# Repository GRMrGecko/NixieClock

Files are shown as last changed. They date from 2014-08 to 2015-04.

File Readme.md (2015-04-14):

#Nixie Tube Clock - Arduino Controlled Clock

I don't have any fun names to put on this project, I haven't thought of one... If you have one, email me.

All details has not been written out, but you can piece together things by going to my blog at http://mrgecko.org and viewing images and docs here.

You would want to use Modified Board to print as I include the needed gerber files and also it has pin outs for power which is useful for adding the bluetooth board.

Many of the parts used is available at https://www.sparkfun.com/wish_lists/83348 I recommend buying the needed resistors from some place where you can order them individually.

To get nixie tubes, I recommend you go on ebay and search for "Nixie Tube IN 14" without quotes.

Power Supply can be ordered from http://www.allspectrum.com/store/nixie-power-supply-high-voltage-switch-mode-dc-dc-converter-kit-95-190vdc-25ma-180vdc-p-521.html
The tube ICs can be purchased from http://www.allspectrum.com/store/74141-nixie-tube-driver-ic-russian-p-211.html, you will need 6.

Look at notes.txt for resister values.

Extended documents available at https://sf.gec.im/d/1c3d227302/

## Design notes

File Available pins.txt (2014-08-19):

12
8
9
4
3

13 - May not be available due to LED

A4
A5
A0
A1
A2
A3

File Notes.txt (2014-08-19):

1K for temp
10k under arduino
27k for nixies

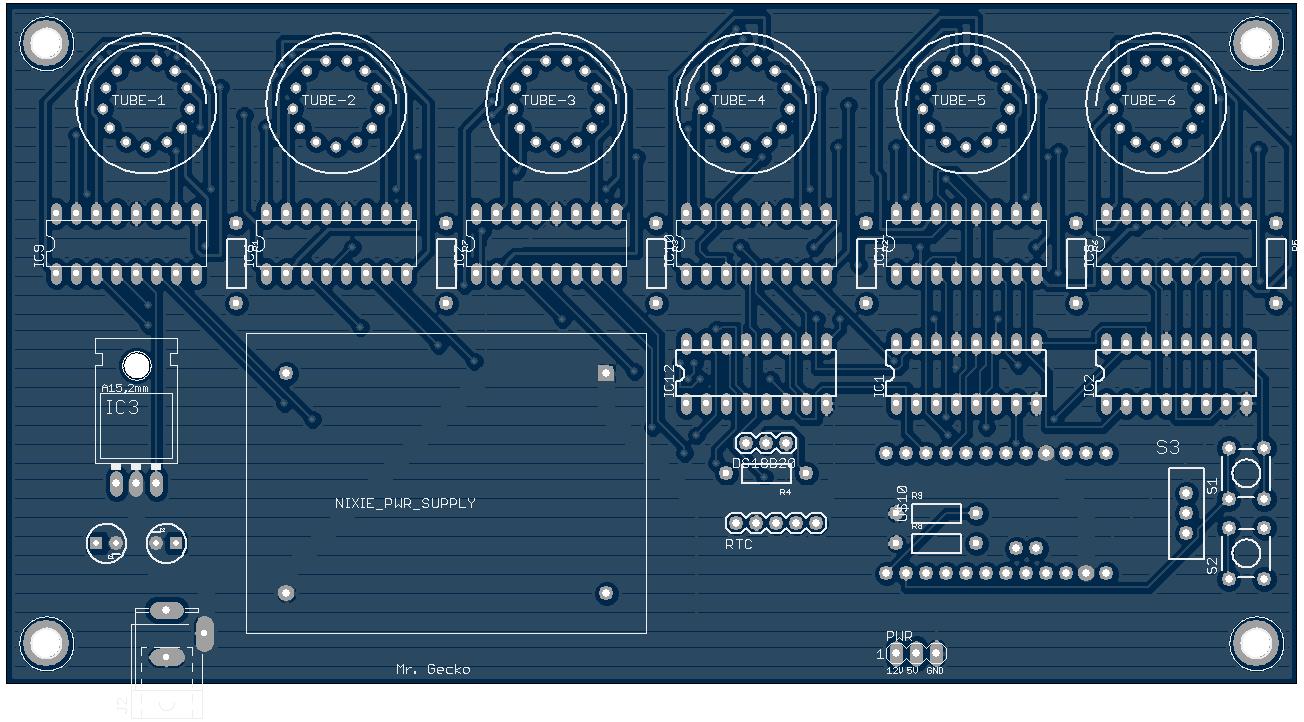
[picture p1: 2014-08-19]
Modified Board/top.png

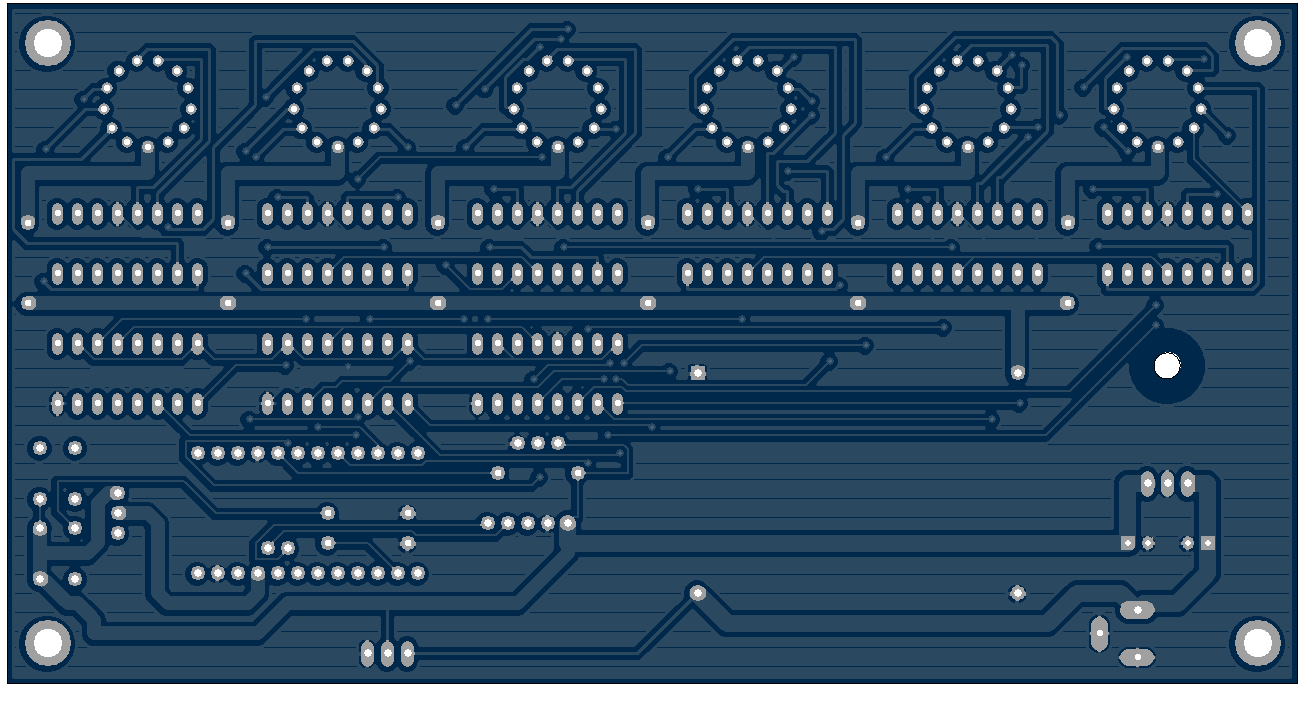
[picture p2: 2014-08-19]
Modified Board/bottom.png

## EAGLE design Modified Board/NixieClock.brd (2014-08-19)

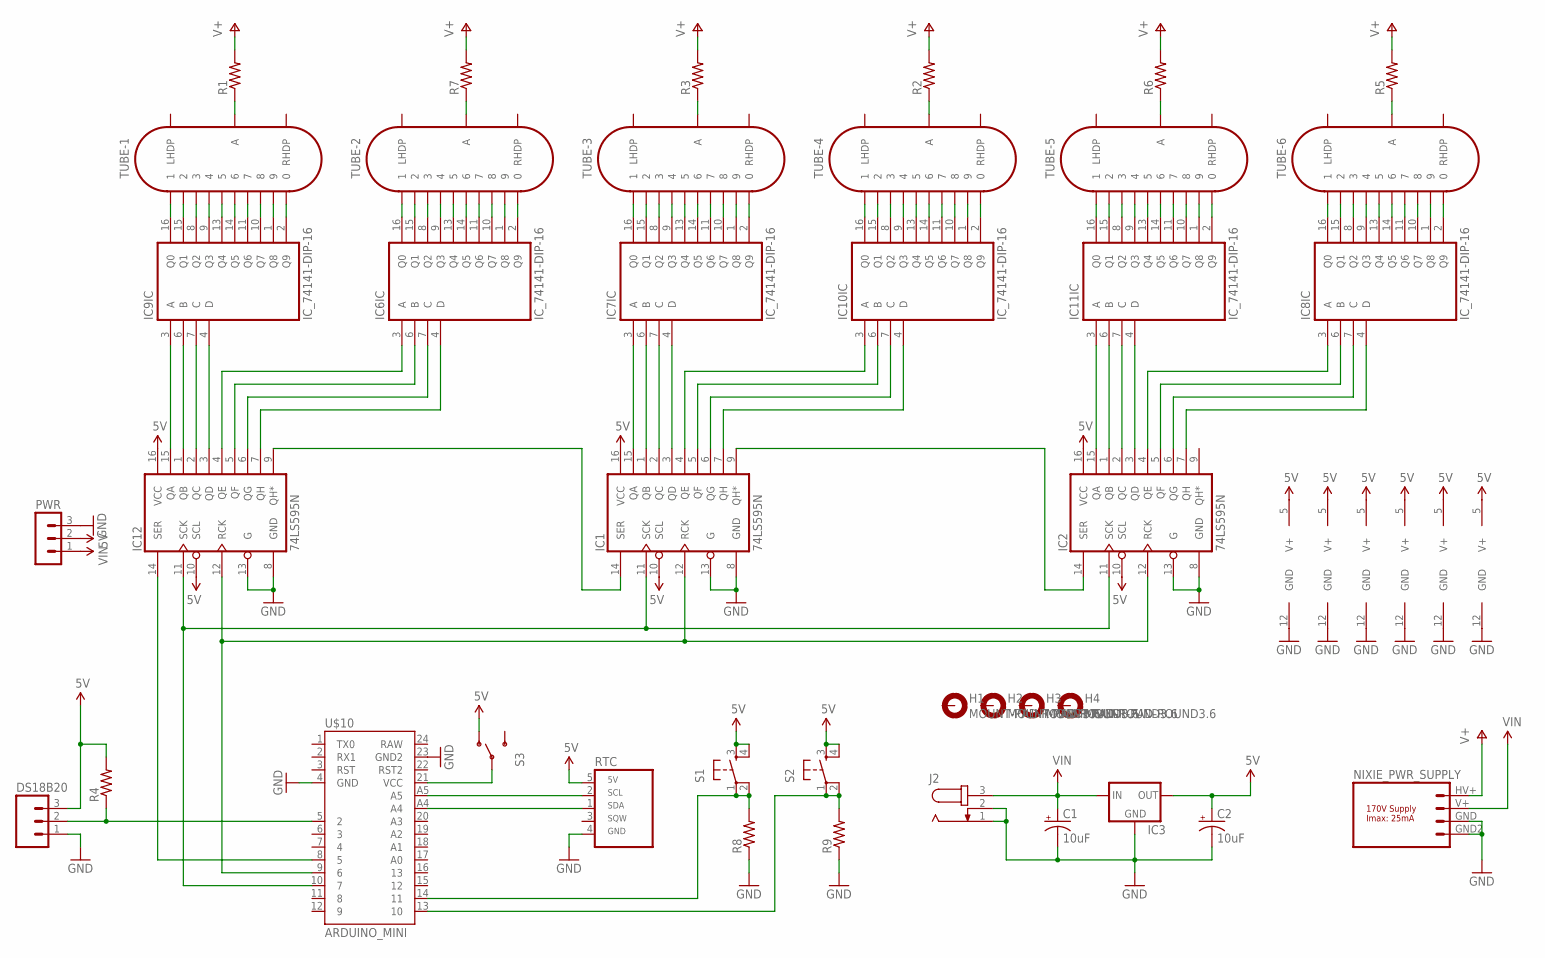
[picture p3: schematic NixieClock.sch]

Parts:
C1, C2: 10uF; CPOL-RADIAL-10UF-25V
DS18B20: DS18B20DS18B20; DS18B20
H1, H2, H3, H4: MOUNT-PAD-ROUND3.6; 3,6-PAD
IC1, IC2, IC12: 74LS595N; DIL16
IC3: V_REG_78XXSIDE; 78XXL
IC6, IC7, IC8, IC9, IC10, IC11: IC_74141-DIP-16; DIL16
J2: JACK-PLUG0; SPC4077
NIXIE_PWR_SUPPLY: NIXIE_PWR_SUPPLYPTH; NIXIE_PWR_SUPPLY
PWR: MA03-1
R1, R2, R3, R4, R5, R6, R7, R8, R9: RESISTORPTH-1/4W; AXIAL-0.4
RTC: SCOTT_RTCPTH; SCOTT_RTC
S1, S2: TAC_SWITCHPTH; TACTILE-PTH
S3: SWITCH-SPDTPTH; SWITCH-SPDT
TUBE-1, TUBE-2, TUBE-3, TUBE-4, TUBE-5, TUBE-6: IN-14
U$10: ARDUINO_MINI

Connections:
5V: C2.1 (+), DS18B20.3 (5V), IC1.10 (SCL), IC1.16 (VCC), IC2.10 (SCL), IC2.16 (VCC), IC3.OUT, IC6.5 (V+), IC7.5 (V+), IC8.5 (V+), IC9.5 (V+), IC10.5 (V+), IC11.5 (V+), IC12.10 (SCL), IC12.16 (VCC), PWR.2, R4.P$2 (2), RTC.5 (5V), S1.3, S1.4, S2.3, S2.4, S3.1 (O)
GND: C1.2 (-), C2.2 (-), DS18B20.1 (GND), IC1.8 (GND), IC1.13 (G), IC2.8 (GND), IC2.13 (G), IC3.GND, IC6.12 (GND), IC7.12 (GND), IC8.12 (GND), IC9.12 (GND), IC10.12 (GND), IC11.12 (GND), IC12.8 (GND), IC12.13 (G), J2.1, J2.2, NIXIE_PWR_SUPPLY.GND (4), NIXIE_PWR_SUPPLY.GND2 (1), PWR.3, R8.P$1 (1), R9.P$1 (1), RTC.4 (GND), U$10.4 (GND), U$10.23 (GND2)
unnamed: R1.P$1 (1), TUBE-1.A
unnamed: R7.P$1 (1), TUBE-2.A
unnamed: R3.P$1 (1), TUBE-3.A
unnamed: R2.P$1 (1), TUBE-4.A
unnamed: R6.P$1 (1), TUBE-5.A
unnamed: R5.P$1 (1), TUBE-6.A
unnamed: IC9.16 (Q0), TUBE-1.1
unnamed: IC9.15 (Q1), TUBE-1.2
unnamed: IC9.8 (Q2), TUBE-1.3
unnamed: IC9.9 (Q3), TUBE-1.4
unnamed: IC9.13 (Q4), TUBE-1.5
unnamed: IC9.14 (Q5), TUBE-1.6
unnamed: IC9.11 (Q6), TUBE-1.7
unnamed: IC9.10 (Q7), TUBE-1.8
unnamed: IC9.1 (Q8), TUBE-1.9
unnamed: IC9.2 (Q9), TUBE-1.0
unnamed: IC6.16 (Q0), TUBE-2.1
unnamed: IC6.15 (Q1), TUBE-2.2
unnamed: IC6.8 (Q2), TUBE-2.3
unnamed: IC6.9 (Q3), TUBE-2.4
unnamed: IC6.13 (Q4), TUBE-2.5
unnamed: IC6.14 (Q5), TUBE-2.6
unnamed: IC6.11 (Q6), TUBE-2.7
unnamed: IC6.10 (Q7), TUBE-2.8
unnamed: IC6.1 (Q8), TUBE-2.9
unnamed: IC6.2 (Q9), TUBE-2.0
unnamed: IC7.16 (Q0), TUBE-3.1
unnamed: IC7.15 (Q1), TUBE-3.2
unnamed: IC7.8 (Q2), TUBE-3.3
unnamed: IC7.9 (Q3), TUBE-3.4
unnamed: IC7.13 (Q4), TUBE-3.5
unnamed: IC7.14 (Q5), TUBE-3.6
unnamed: IC7.11 (Q6), TUBE-3.7
unnamed: IC7.10 (Q7), TUBE-3.8
unnamed: IC7.1 (Q8), TUBE-3.9
unnamed: IC7.2 (Q9), TUBE-3.0
unnamed: IC10.16 (Q0), TUBE-4.1
unnamed: IC10.15 (Q1), TUBE-4.2
unnamed: IC10.8 (Q2), TUBE-4.3
unnamed: IC10.9 (Q3), TUBE-4.4
unnamed: IC10.13 (Q4), TUBE-4.5
unnamed: IC10.14 (Q5), TUBE-4.6
unnamed: IC10.11 (Q6), TUBE-4.7
unnamed: IC10.10 (Q7), TUBE-4.8
unnamed: IC10.1 (Q8), TUBE-4.9
unnamed: IC10.2 (Q9), TUBE-4.0
unnamed: IC11.16 (Q0), TUBE-5.1
unnamed: IC11.15 (Q1), TUBE-5.2
unnamed: IC11.8 (Q2), TUBE-5.3
unnamed: IC11.9 (Q3), TUBE-5.4
unnamed: IC11.13 (Q4), TUBE-5.5
unnamed: IC11.14 (Q5), TUBE-5.6
unnamed: IC11.11 (Q6), TUBE-5.7
unnamed: IC11.10 (Q7), TUBE-5.8
unnamed: IC11.1 (Q8), TUBE-5.9
unnamed: IC11.2 (Q9), TUBE-5.0
unnamed: IC8.16 (Q0), TUBE-6.1
unnamed: IC8.15 (Q1), TUBE-6.2
unnamed: IC8.8 (Q2), TUBE-6.3
unnamed: IC8.9 (Q3), TUBE-6.4
unnamed: IC8.13 (Q4), TUBE-6.5
unnamed: IC8.14 (Q5), TUBE-6.6
unnamed: IC8.11 (Q6), TUBE-6.7
unnamed: IC8.10 (Q7), TUBE-6.8
unnamed: IC8.1 (Q8), TUBE-6.9
unnamed: IC8.2 (Q9), TUBE-6.0
unnamed: IC1.1 (QB), IC7.6 (B)
unnamed: IC1.2 (QC), IC7.7 (C)
unnamed: IC1.3 (QD), IC7.4 (D)
unnamed: IC1.15 (QA), IC7.3 (A)
unnamed: IC9.6 (B), IC12.1 (QB)
unnamed: IC9.7 (C), IC12.2 (QC)
unnamed: IC9.4 (D), IC12.3 (QD)
unnamed: IC9.3 (A), IC12.15 (QA)
unnamed: IC2.1 (QB), IC11.6 (B)
unnamed: IC2.2 (QC), IC11.7 (C)
unnamed: IC2.3 (QD), IC11.4 (D)
unnamed: IC2.15 (QA), IC11.3 (A)
unnamed: IC6.3 (A), IC12.4 (QE)
unnamed: IC6.6 (B), IC12.5 (QF)
unnamed: IC6.7 (C), IC12.6 (QG)
unnamed: IC6.4 (D), IC12.7 (QH)
unnamed: IC1.14 (SER), IC12.9 (QH*)
unnamed: IC1.9 (QH*), IC2.14 (SER)
unnamed: IC1.4 (QE), IC10.3 (A)
unnamed: IC1.5 (QF), IC10.6 (B)
unnamed: IC1.6 (QG), IC10.7 (C)
unnamed: IC1.7 (QH), IC10.4 (D)
unnamed: IC12.14 (SER), U$10.8 (5)
unnamed: IC2.4 (QE), IC8.3 (A)
unnamed: IC2.5 (QF), IC8.6 (B)
unnamed: IC2.6 (QG), IC8.7 (C)
unnamed: IC2.7 (QH), IC8.4 (D)
unnamed: IC1.11 (SCK), IC2.11 (SCK), IC12.11 (SCK), U$10.10 (7)
unnamed: IC1.12 (RCK), IC2.12 (RCK), IC12.12 (RCK), U$10.9 (6)
unnamed: R9.P$2 (2), S2.1, S2.2, U$10.13 (10)
unnamed: DS18B20.2 (DS), R4.P$1 (1), U$10.5 (2)
unnamed: RTC.2 (SCL), U$10.A5
unnamed: RTC.1 (SDA), U$10.A4
unnamed: S3.2, U$10.21 (VCC)
unnamed: R8.P$2 (2), S1.1, S1.2, U$10.14 (11)
V+: NIXIE_PWR_SUPPLY.HV+ (3), R1.P$2 (2), R2.P$2 (2), R3.P$2 (2), R5.P$2 (2), R6.P$2 (2), R7.P$2 (2)
VIN: C1.1 (+), IC3.IN, J2.3, NIXIE_PWR_SUPPLY.V+ (2), PWR.1

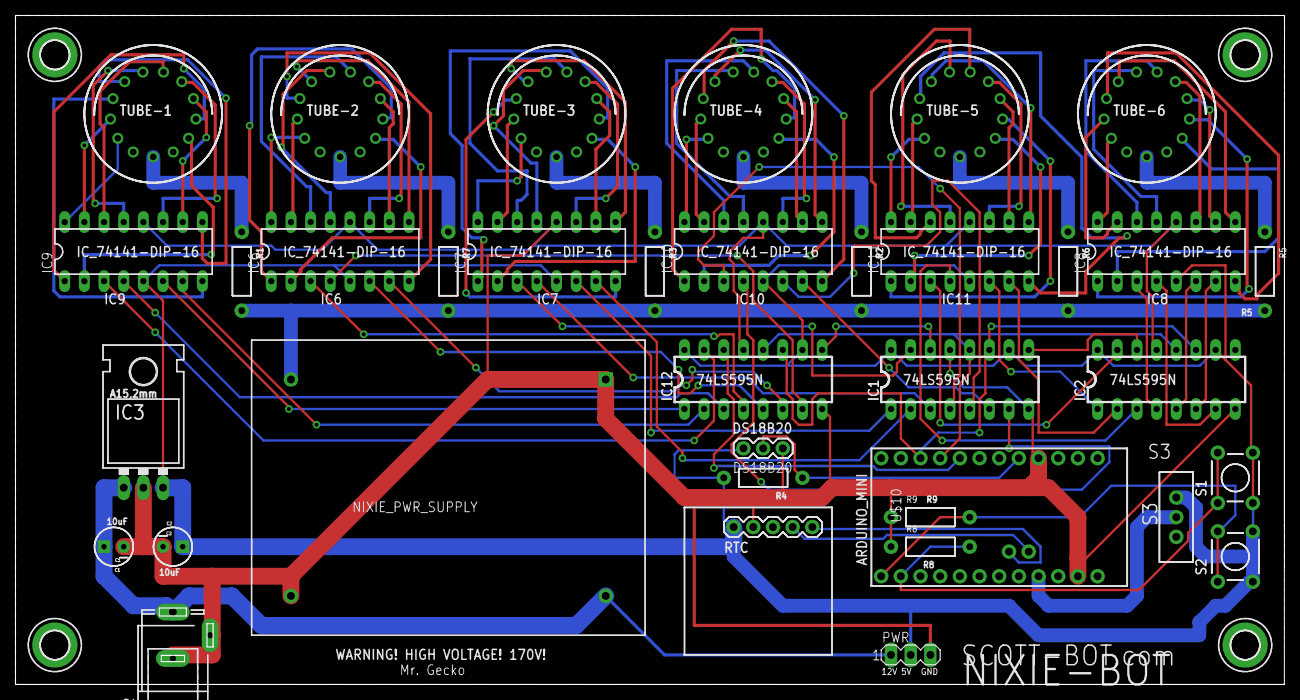
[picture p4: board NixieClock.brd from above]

Board: 2 copper layers, 163.8 x 86.4 mm, 40 parts (0 on the bottom side), 105 nets.

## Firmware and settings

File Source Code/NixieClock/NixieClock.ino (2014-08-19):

//
//  Nixie Clock.ino
//
//  Created by Mr. Gecko's Media (James Coleman) on 7/23/14.
//  No Copyright Claimed. Public Domain.
//

#include <Wire.h>
#include "RTClib.h"
#include "OneWire.h"

#include "Nixies.h"
#include "Registers.h"

const unsigned int button1Pin = 10;
const unsigned int button2Pin = 11;
unsigned int button1State = 0;
unsigned int button2State = 0;

OneWire ds(2); // Temperature Sensor on pin 2
RTC_DS1307 RTC;

unsigned int serialPin = 5;
unsigned int serialClockPin = 7;
unsigned int registerClockPin = 6;

Nixies nixies;

void setup() {
	Serial.begin(9600);
	Wire.begin();
	
	RTC.begin();
	if (!RTC.isrunning()) {
		Serial.println("RTC needs to be set");
		RTC.adjust(DateTime(__DATE__, __TIME__));
	}
	
	pinMode(button1Pin, INPUT);
	pinMode(button2Pin, INPUT);       
	
	nixies.initialize(serialPin, serialClockPin, registerClockPin, 6);
}

void parseSerialData(char *data) {
	char *originalData = data;
	char *array[10];
	int arrayCount = 0;
	
	char *parse = strtok(data, ",");
	while (parse!=NULL) {
		array[arrayCount] = parse;
		arrayCount++;
		if (arrayCount>=9)
			return;
		parse = strtok(NULL, ",");
	}
	array[arrayCount] = NULL;
	
	if (arrayCount==0)
		return;
	if (strcmp(array[0],"pi")==0) {//Ping
		Serial.println(originalData);
	} else if (strcmp(array[0],"st")==0 && arrayCount==8) {// Set Time
		delay(atoi(array[7]));
		RTC.adjust(DateTime(atoi(array[1])/*Year*/, atoi(array[2])/*Month*/, atoi(array[3])/*Day*/, atoi(array[4])/*Hour*/, atoi(array[5])/*Minute*/, atoi(array[6])/*Second*/));
	} else if (strcmp(array[0],"dp")==0 && arrayCount==3) { // Display for MS.
		char *display = array[1];
		int length = strlen(display);
		if (length>6)
			return;
		for (int i=0; i<6; i++) {
			int value;
			if (i<length) {
				char digit = display[i];
				if (digit==' ') {
					value = 10;
				} else {
					value = atoi(&digit);
				}
			} else {
				value = 10;
			}
			nixies.setNixie(5-i, value);
		}
		nixies.update();
		delay(atoi(array[2]));
	} else if (strcmp(array[0],"test")==0) { // Run tests
		testTubes();
	} else if (strcmp(array[0],"temp")==0) { // Display Temperature
		displayTemperature();
	} else if (strcmp(array[0],"readtemp")==0) { // Display Temperature
		float temperature = getTemperatureFahrenheit();
		Serial.println(temperature);
	} else if (strcmp(array[0],"readtempc")==0) { // Display Temperature
		float temperature = getTemperature();
		Serial.println(temperature);
	}
}

void processSerialData() {
	unsigned long startRead = millis();
	char *bytesRead = (char *)malloc(50);
	int bytesLength = 0;
	bool goodRead = true;
	while (1) {
		if (Serial.available()) {
			char byteRead = Serial.read();
			// If we receive a end line, we received the response.
			if (byteRead=='\r')
				continue;
			if (byteRead=='\n')
				break;
			bytesRead[bytesLength] = byteRead;
			bytesLength++;
			// We don't want a buffer overrun. The responses from the bluetooth board is usually 3 characters long.
			if (bytesLength>=49) {
				goodRead = false;
				break;
			}
		}
		// Insure there isn't a error in reading and this doesn't continue reading infinite.
		if ((millis()-startRead)>=1000) {
			goodRead = false;
			break;
		}
	}
	bytesRead[bytesLength] = '\0';
	if (goodRead) {
		parseSerialData(bytesRead);
	}
	free(bytesRead);
}

void displayTemperature() {
	int temperature = getTemperatureFahrenheit();
	
	nixies.setNixie(5, temperature/10);
	nixies.setNixie(4, temperature%10);
	nixies.setNixie(3, 10);
	nixies.setNixie(2, 10);
	nixies.setNixie(1, 10);
	nixies.setNixie(0, 10);
	nixies.update();
	delay(2000);
}

void testTubes() {
	// Test every digit
	for (int i=0; i<30; i++) {
		nixies.setNixie(0, i%10);
		nixies.setNixie(1, (i+1)%10);
		nixies.setNixie(2, (i+2)%10);
		nixies.setNixie(3, (i+3)%10);
		nixies.setNixie(4, (i+4)%10);
		nixies.setNixie(5, (i+5)%10);
		nixies.update();
		delay(500);
	}
	// Test setting to blank
	nixies.setNixie(0, 10);
	nixies.setNixie(1, 10);
	nixies.setNixie(2, 10);
	nixies.setNixie(3, 10);
	nixies.setNixie(4, 10);
	nixies.setNixie(5, 10);
	nixies.update();
	delay(1000);
}

void displayTime() {
	DateTime now = RTC.now();
	int hour = now.hour();
	if (hour>12)
		hour -= 12;
	if (hour==0)
		hour = 12;
	int minute = now.minute();
	int second = now.second();
	
	nixies.setNixie(5, hour/10);
	nixies.setNixie(4, hour%10);
	nixies.setNixie(3, minute/10);
	nixies.setNixie(2, minute%10);
	nixies.setNixie(1, second/10);
	nixies.setNixie(0, second%10);
	nixies.update();
}

void loop() {
	if (Serial.available()) {
		processSerialData();
	}
	
	int state1 = digitalRead(button1Pin);
	if (state1!=button1State && state1==HIGH) {
		//displayTemperature();
		Serial.println("b1"); // Send button press to serial.
		button1State = state1;
	} else if (state1!=button1State && state1==LOW) {
		button1State = state1;
	}
	int state2 = digitalRead(button2Pin);
	if (state2!=button2State && state2==HIGH) {
		testTubes();
		Serial.println("b2"); // Send button press to serial.
		button2State = state2;
	} else if (state2!=button2State && state2==LOW) {
		button2State = state2;
	}
	
	displayTime();
}

// Code for this function from http://bildr.org/2011/07/ds18b20-arduino/
// Copyright (c) 2010 bildr community
float getTemperature() {
	//returns the temperature from one DS18S20 in DEG Celsius
	byte data[12];
	byte addr[8];
	
	if (!ds.search(addr)) {
		//no more sensors on chain, reset search
		ds.reset_search();
		return -1000;
	}
	
	if (OneWire::crc8(addr, 7)!=addr[7]) {
		Serial.println("CRC is not valid!");
		return -1000;
	}

	if (addr[0]!=0x10 && addr[0]!=0x28) {
		Serial.print("Device is not recognized");
		return -1000;
	}

	ds.reset();
	ds.select(addr);
	ds.write(0x44,1); // start conversion, with parasite power on at the end

	byte present = ds.reset();
	ds.select(addr);
	ds.write(0xBE); // Read Scratchpad


	for (int i=0; i<9; i++) { // we need 9 bytes
		data[i] = ds.read();
	}

	ds.reset_search();

	byte MSB = data[1];
	byte LSB = data[0];

	float tempRead = ((MSB << 8) | LSB); //using two's compliment
	float TemperatureSum = tempRead / 16;

	return TemperatureSum;
}

float getTemperatureFahrenheit() {
	float temperature = getTemperature();
	return (temperature*(9.0/5.0))+32;
}

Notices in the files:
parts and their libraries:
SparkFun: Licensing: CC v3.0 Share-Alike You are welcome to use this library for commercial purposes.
